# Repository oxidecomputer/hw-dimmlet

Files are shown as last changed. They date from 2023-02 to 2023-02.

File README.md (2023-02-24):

# hw-dimmlet



Breaks out I2C connections to 2x DIMM sockets to a PMOD i2c interface for SPD work.
Works well with gimletlet

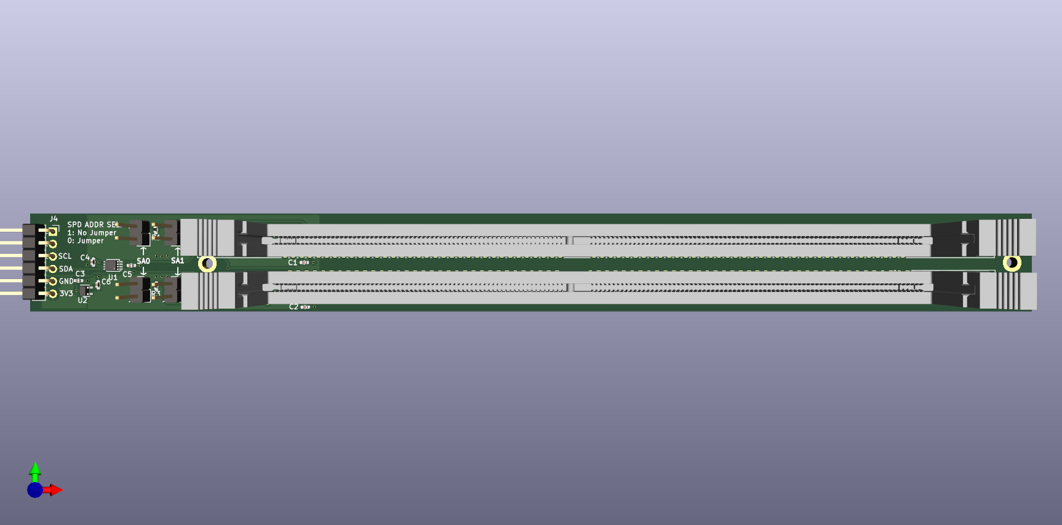
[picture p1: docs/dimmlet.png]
render


# Status
Rev1 required MCNs as documented. CAD was updated to resolve these
issues but new CAD was not actually built since the reworked rev1s
served their purpose

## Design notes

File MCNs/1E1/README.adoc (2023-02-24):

= Dimmlet MCN rev1-E1

== Rationale

Upon bringing up the rev1 dimmlet board, it was discovered that U1, the TXS0102 part was designed in backwards, and there's a constraint that Vccb >= Vcca whereas the design had Vcca > Vccb. It was confirmed that this does not work.

In order to salvage the boards, the following rework was identified in order to correct this issue.

Since these were hand-assembled, this issue was identified and corrected on the first unit and the rework was applied to each subsequent board that was built.

== Material/Tools

Nothing special except some 30ga wire, optical magnification, and tweezers.

== Physical Rework steps

The overview of the rework is that we're going to cut a trace (GND pin) under U1, lift the OE pin so we can tack it to enabled, install the U1 rotated 180 degrees

These steps assume an un-populated U1 location.

. Lift OE pin. Bend pin6 up so that it won't be soldered to the board when the chip is installed.
. Cut GND trace as shown below.

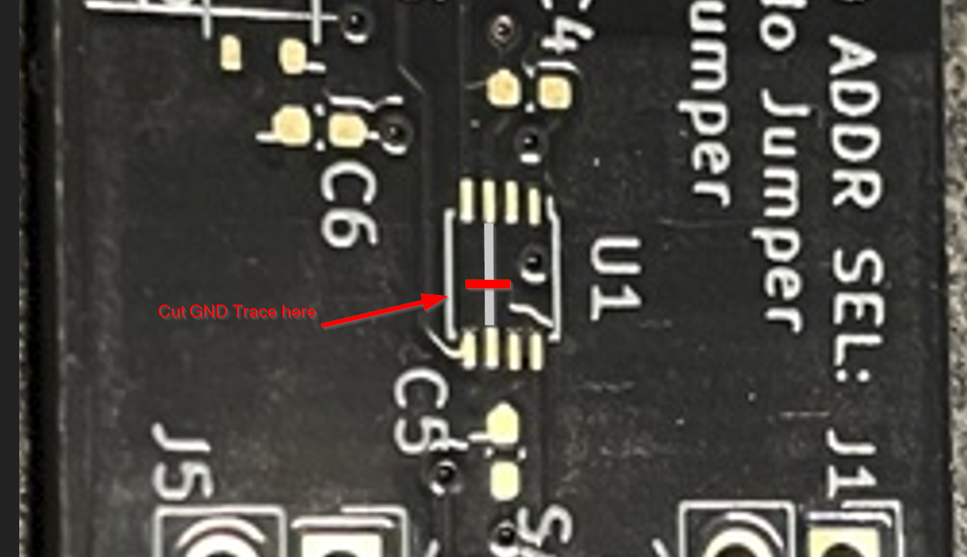
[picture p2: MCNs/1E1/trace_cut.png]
Trace Cut


. Install the chip with pin1 near C5.

. Add a jumper wire from U1 pin3 (Vcca) to flown/lifted U1 pin6 (OE) Magenta line in image below.

. Add a jumper wire from C5's ground pin to U1 pin2 (Gnd) Cyan line in image below.

. Optional: After testing to confirm functionality, it may be desireable to put superglue or epoxy on this rework to increase it's strength.

. Re-label board as rev1-E1

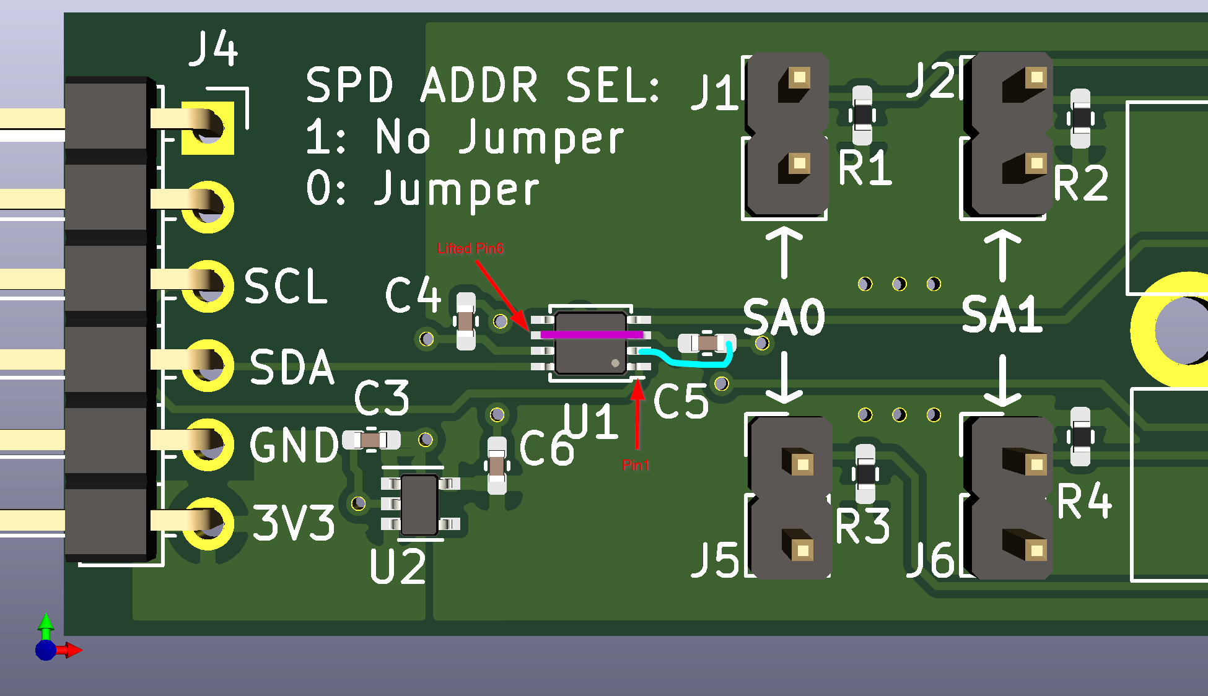
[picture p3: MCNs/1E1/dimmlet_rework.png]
Completed Rework


== Determinations

PCB CAD and schematic were both updated to allow a rev2 spin of this board without rework even though no rev2 spin is planned.

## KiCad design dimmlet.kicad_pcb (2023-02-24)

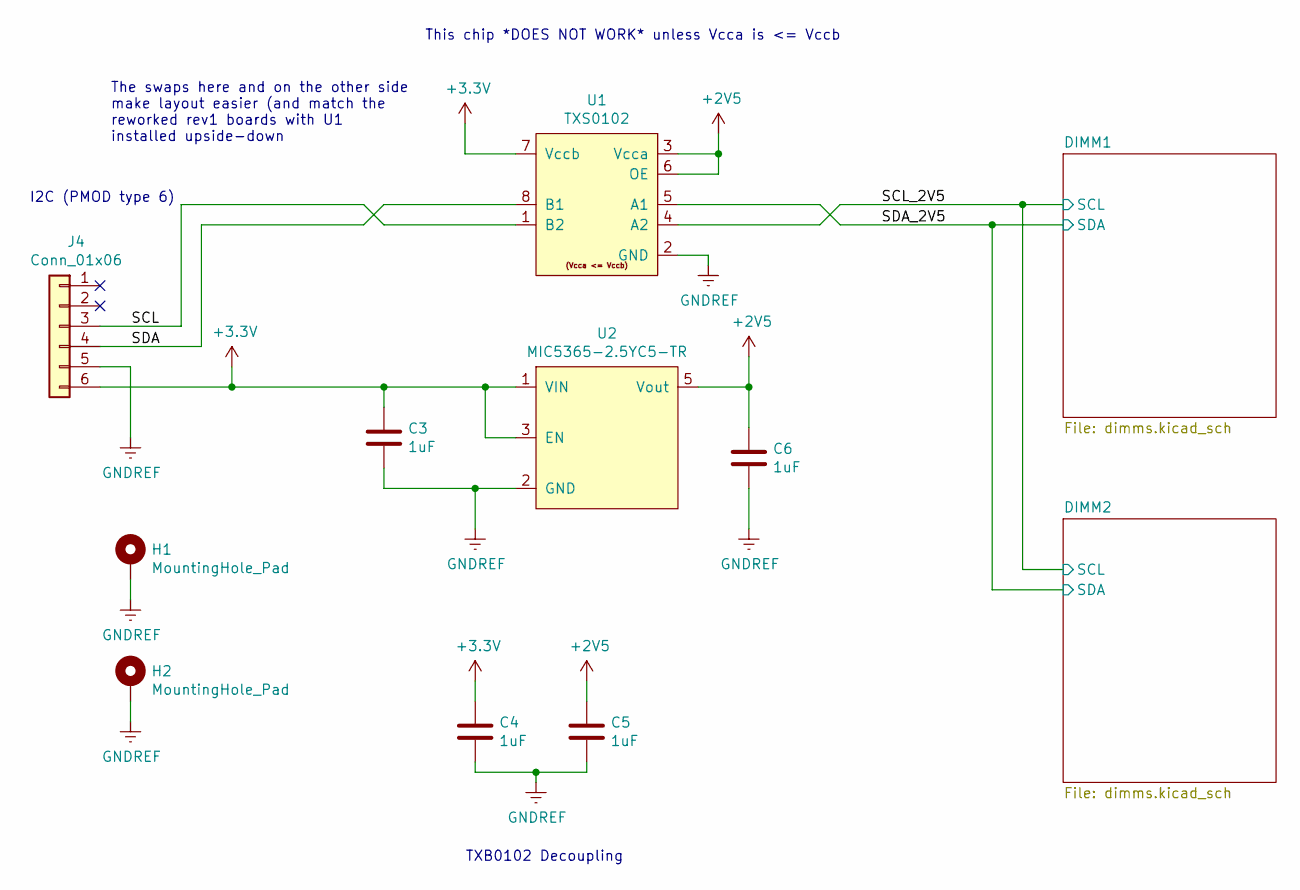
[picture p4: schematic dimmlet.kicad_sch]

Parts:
C3, C4, C5, C6: 1uF; C_0402_1005Metric_Pad0.74x0.62mm_HandSolder
H1, H2: MountingHole_Pad; MountingHole_2.2mm_M2_DIN965_Pad
J4: Conn_01x06; PMOD_6pin_peripheral_horizontal
U1: ‎TXS0102; VSSOP-8_2.4x2.1mm_P0.5mm
U2: ‎MIC5365-2.5YC5-TR; SOT-353_SC-70-5

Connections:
+2V5: C5.1, C6.1, U1.3 (Vcca), U1.6 (OE), U2.5 (Vout); also elsewhere on the board
+3V3: C3.1, C4.1, J4.6, U1.7 (Vccb), U2.1 (VIN), U2.3 (EN)
/SCL: J4.3, U1.1 (B2)
/SCL_2V5: U1.4 (A2); also elsewhere on the board
/SDA: J4.4, U1.8 (B1)
/SDA_2V5: U1.5 (A1); also elsewhere on the board
GNDREF: C3.2, C4.2, C5.2, C6.2, H1.1, H2.1, J4.5, U1.2 (GND), U2.2 (GND); also elsewhere on the board

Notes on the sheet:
The swaps here and on the other side make layout easier (and match the reworked rev1 boards with U1 installed upside-down
I2C (PMOD type 6)
TXB0102 Decoupling
This chip *DOES NOT WORK* unless Vcca is <= Vccb

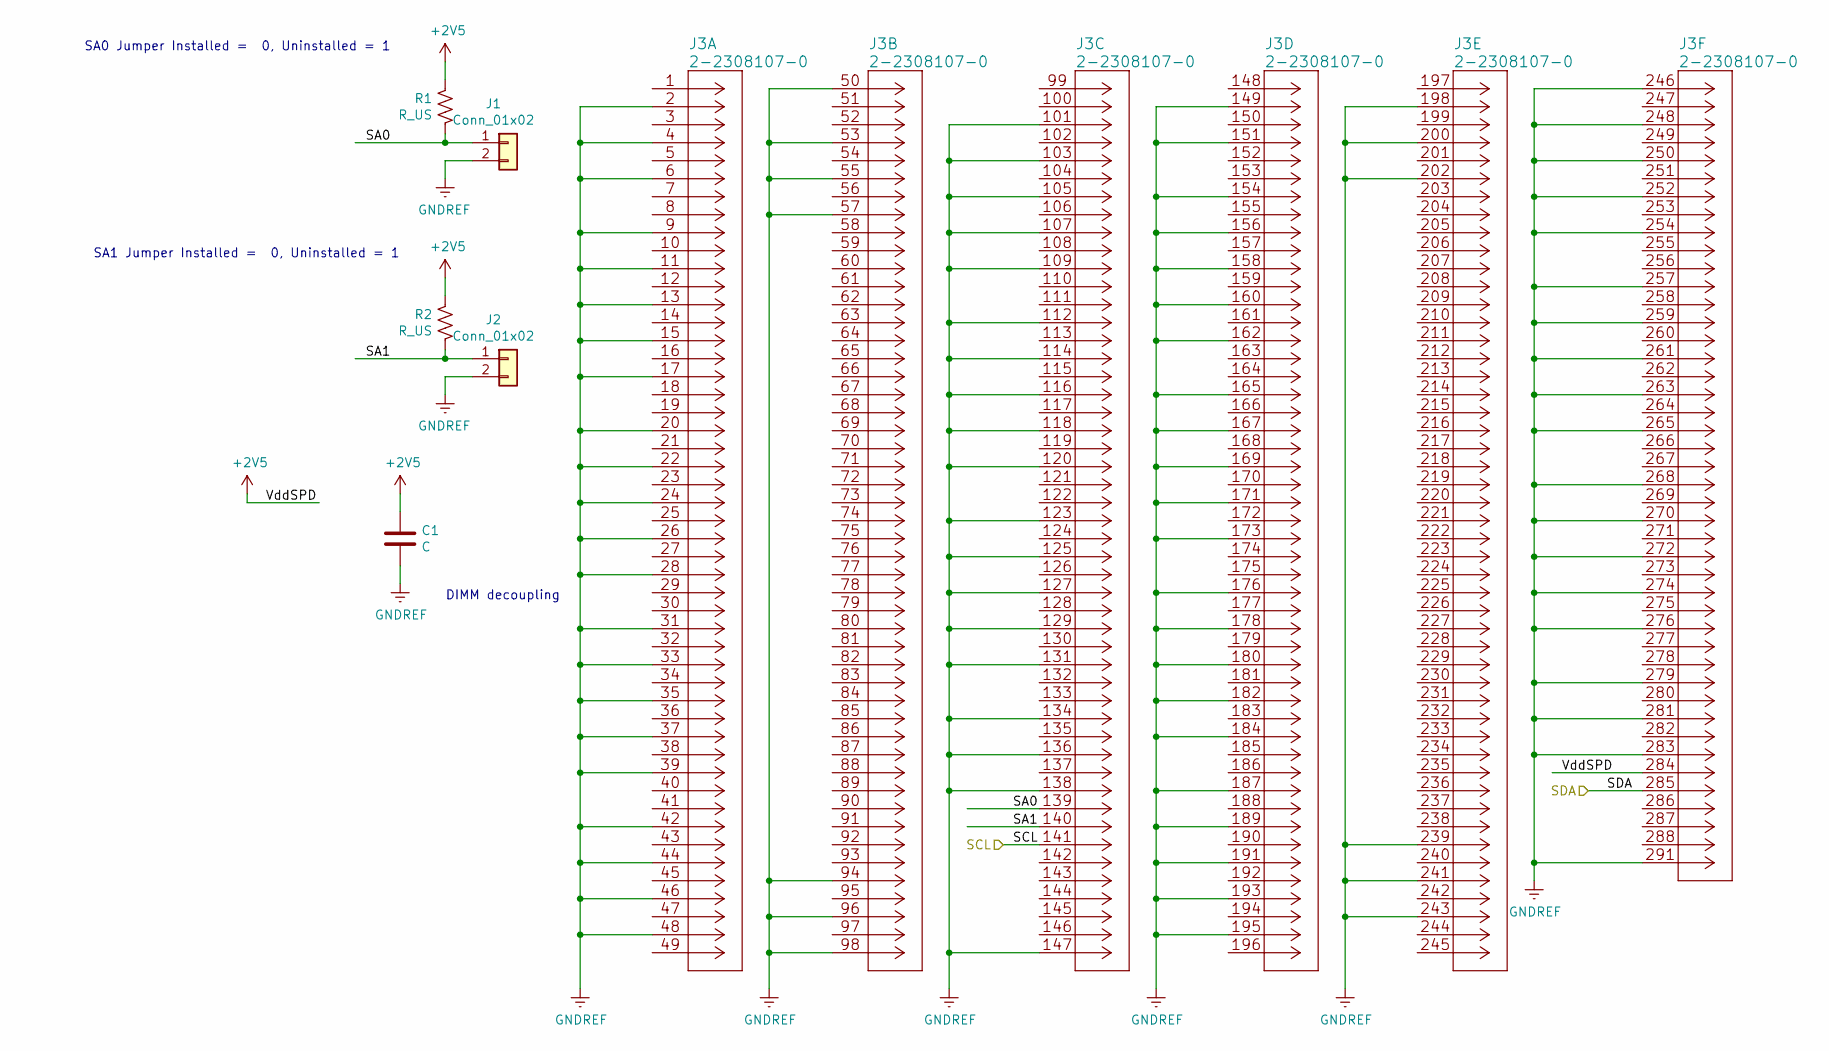
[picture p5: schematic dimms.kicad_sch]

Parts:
C1: C; C_0402_1005Metric_Pad0.74x0.62mm_HandSolder
J1, J2: Conn_01x02; PinHeader_1x02_P2.54mm_Vertical
J3: 2-2308107-0
R1, R2: R_US; R_0402_1005Metric_Pad0.72x0.64mm_HandSolder

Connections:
+2V5: C1.1, J3.284, R1.1, R2.1; also elsewhere on the board
/DIMM1/SA0: J1.1, J3.139, R1.2
/DIMM1/SA1: J2.1, J3.140, R2.2
/SCL_2V5: J3.141; also elsewhere on the board
/SDA_2V5: J3.285; also elsewhere on the board
GNDREF: C1.2, J1.2, J2.2, J3.2, J3.4, J3.6, J3.9, J3.11, J3.13, J3.15, J3.17, J3.20, J3.22, J3.24, J3.26, J3.28, J3.31, J3.33, J3.35, J3.37, J3.39, J3.42, J3.44, J3.46, J3.48, J3.50, J3.53, J3.55, J3.57, J3.94, J3.96, J3.98, J3.101, J3.103, J3.105, J3.107, J3.109, J3.112, J3.114, J3.116, J3.118, J3.120, J3.123, J3.125, J3.127, J3.129, J3.131, J3.134, J3.136, J3.138, J3.147, J3.149, J3.151, J3.154, J3.156, J3.158, J3.160, J3.162, J3.165, J3.167, J3.169, J3.171, J3.173, J3.176, J3.178, J3.180, J3.182, J3.184, J3.187, J3.189, J3.191, J3.193, J3.195, J3.198, J3.200, J3.202, J3.239, J3.241, J3.243, J3.246, J3.248, J3.250, J3.252, J3.254, J3.257, J3.259, J3.261, J3.263, J3.265, J3.268, J3.270, J3.272, J3.274, J3.276, J3.279, J3.281, J3.283, J3.291; also elsewhere on the board

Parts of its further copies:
C2: C; C_0402_1005Metric_Pad0.74x0.62mm_HandSolder
J5, J6: Conn_01x02; PinHeader_1x02_P2.54mm_Vertical
J7: 2-2308107-0
R3, R4: R_US; R_0402_1005Metric_Pad0.72x0.64mm_HandSolder

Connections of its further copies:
+2V5: C2.1, J7.284, R3.1, R4.1; also elsewhere on the board
/DIMM2/SA0: J5.1, J7.139, R3.2
/DIMM2/SA1: J6.1, J7.140, R4.2
/SCL_2V5: J7.141; also elsewhere on the board
/SDA_2V5: J7.285; also elsewhere on the board
GNDREF: C2.2, J5.2, J6.2, J7.2, J7.4, J7.6, J7.9, J7.11, J7.13, J7.15, J7.17, J7.20, J7.22, J7.24, J7.26, J7.28, J7.31, J7.33, J7.35, J7.37, J7.39, J7.42, J7.44, J7.46, J7.48, J7.50, J7.53, J7.55, J7.57, J7.94, J7.96, J7.98, J7.101, J7.103, J7.105, J7.107, J7.109, J7.112, J7.114, J7.116, J7.118, J7.120, J7.123, J7.125, J7.127, J7.129, J7.131, J7.134, J7.136, J7.138, J7.147, J7.149, J7.151, J7.154, J7.156, J7.158, J7.160, J7.162, J7.165, J7.167, J7.169, J7.171, J7.173, J7.176, J7.178, J7.180, J7.182, J7.184, J7.187, J7.189, J7.191, J7.193, J7.195, J7.198, J7.200, J7.202, J7.239, J7.241, J7.243, J7.246, J7.248, J7.250, J7.252, J7.254, J7.257, J7.259, J7.261, J7.263, J7.265, J7.268, J7.270, J7.272, J7.274, J7.276, J7.279, J7.281, J7.283, J7.291; also elsewhere on the board

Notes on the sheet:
DIMM decoupling
SA0 Jumper Installed = 0, Uninstalled = 1
SA1 Jumper Installed = 0, Uninstalled = 1

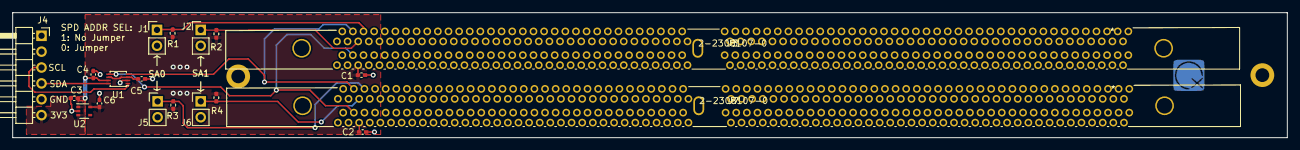
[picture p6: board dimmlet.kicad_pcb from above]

Board: 2 copper layers, 204.0 x 20.0 mm, 21 parts (0 on the bottom side), 11 nets.

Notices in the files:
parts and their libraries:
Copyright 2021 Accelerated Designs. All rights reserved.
